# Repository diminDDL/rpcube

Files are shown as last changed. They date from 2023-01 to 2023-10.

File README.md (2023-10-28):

# rpcube

Welcome to `rpcube`, the ultimate compact solution for integrating the RP2040 into your designs seamlessly. This project presents an all-in-one small BGA package that brings the powerful RP2040 to your fingertips. 

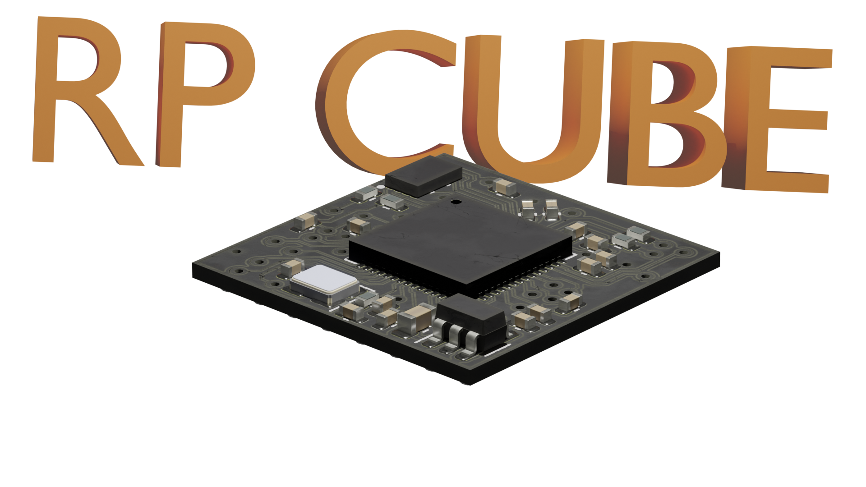
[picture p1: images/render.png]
rpcube Top View


## Features

- **Compact Size**: With a tiny footprint of just 16.5x16.5mm, `rpcube` is designed to fit into the smallest of spaces while providing the full capabilities of the RP2040.

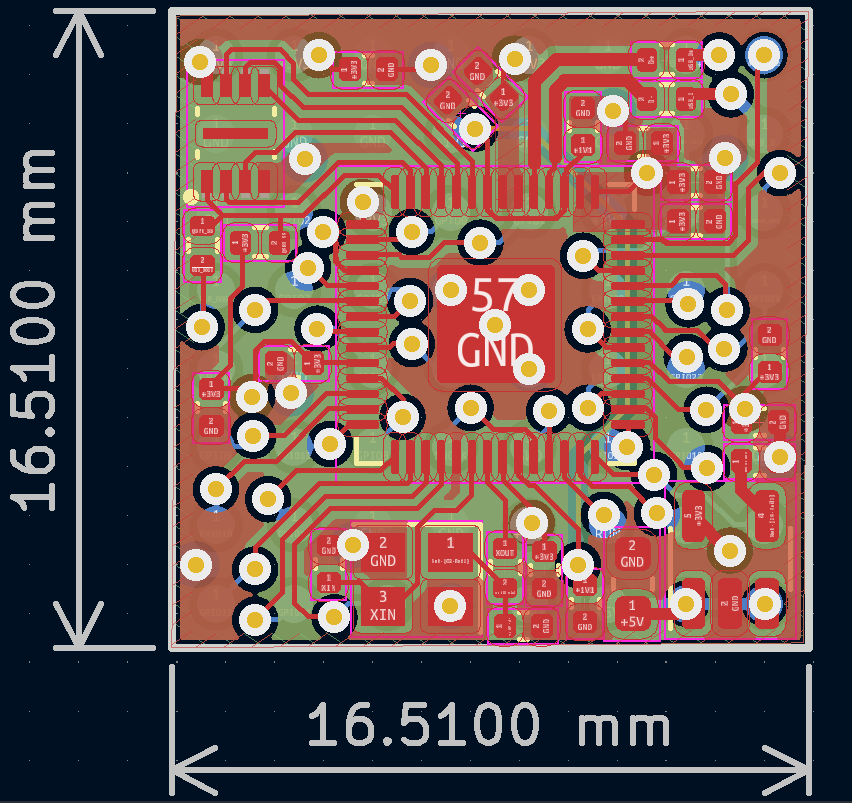
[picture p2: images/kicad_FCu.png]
rpcube Bottom View
  

- **Integrated Components**: The package includes EEPROM, all necessary bypass capacitors, and an LDO to allow for direct 5V input, stepping it down internally.
- **Full GPIO Access**: All GPIOs as well as the SWD lines of the RP2040 are exposed and accessible, ensuring you can leverage the full power of the microcontroller for your projects.
- **Versatile Assembly Options**: Whether you prefer to use solder paste and stencils or go for manual soldering with an iron, `rpcube` accommodates various assembly methods to suit your workflow:
  - **Top Side Assembly**: Begin by assembling the top side using solder paste and hot air or a reflow oven.
  - **Bottom Balls Creation**: Create the bottom balls using a soldering iron with flux and a substantial amount of solder, or stack several stencils to dispense ample solder paste, then blast it with hot air for balls to form.
  - **Target PCB Solder Paste Method**: You can use the same stencil as for the bottom side on the target board, or if you already have the balls done, use just a bit of flux and reflow, the balls will attach themselves.
  - **Target PCB Via in Pad Integration**: You can also use untented vias in your target PCB. Incorporate untented vias in the places of the balls and solder them one by one with an iron.
  - **Wire Attachment for Prototyping**: Alternatively, attach wires directly to `rpcube` for quick and easy point-to-point prototyping.

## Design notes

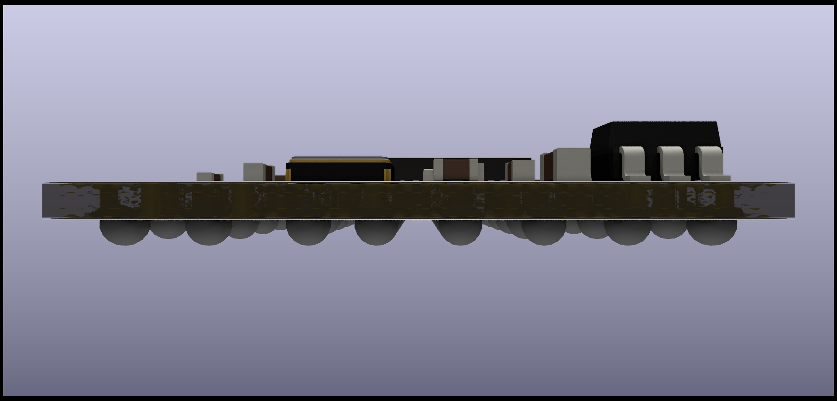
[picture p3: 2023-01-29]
images/3D_side.png

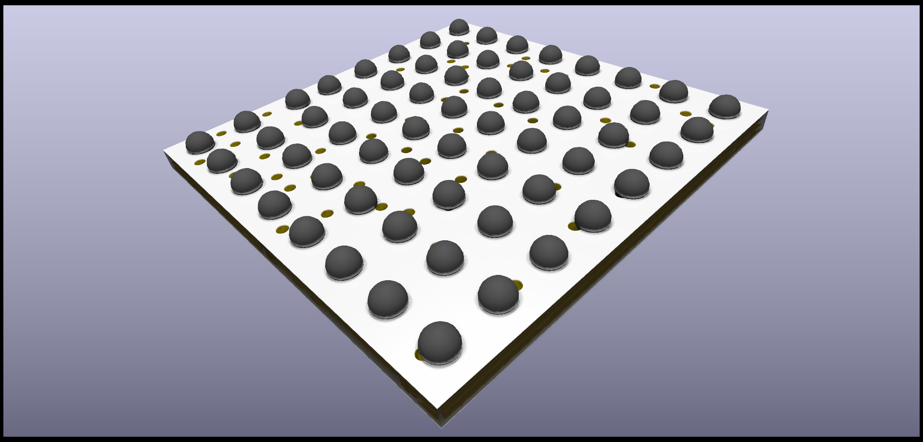
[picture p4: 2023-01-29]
images/3D_bottom.png

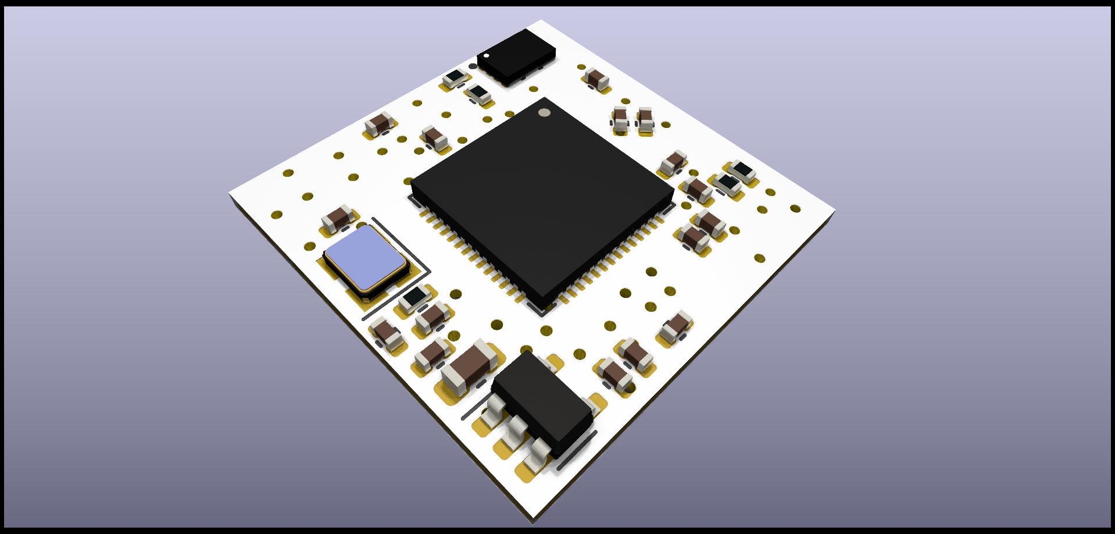
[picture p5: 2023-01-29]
images/3D_front.png

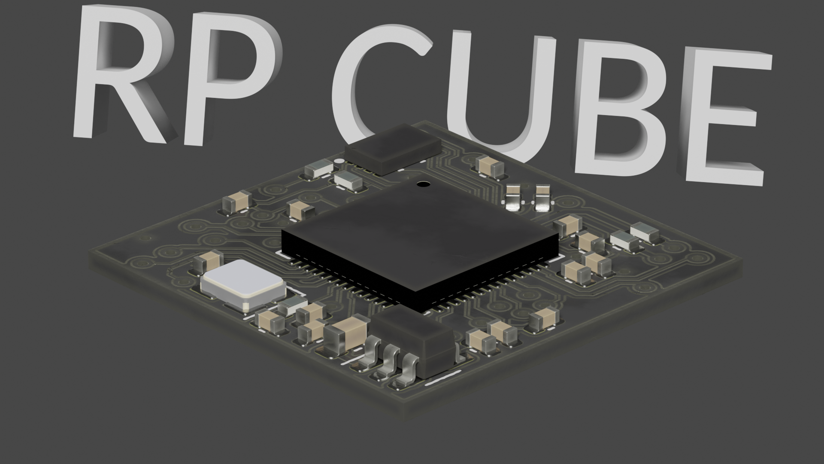
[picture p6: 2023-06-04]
images/untitled2.png

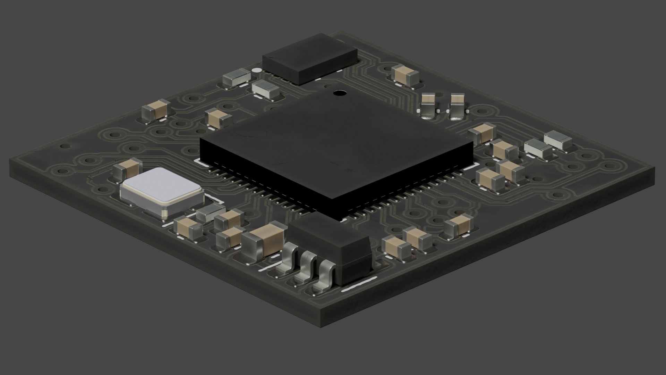
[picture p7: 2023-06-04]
images/untitled.png

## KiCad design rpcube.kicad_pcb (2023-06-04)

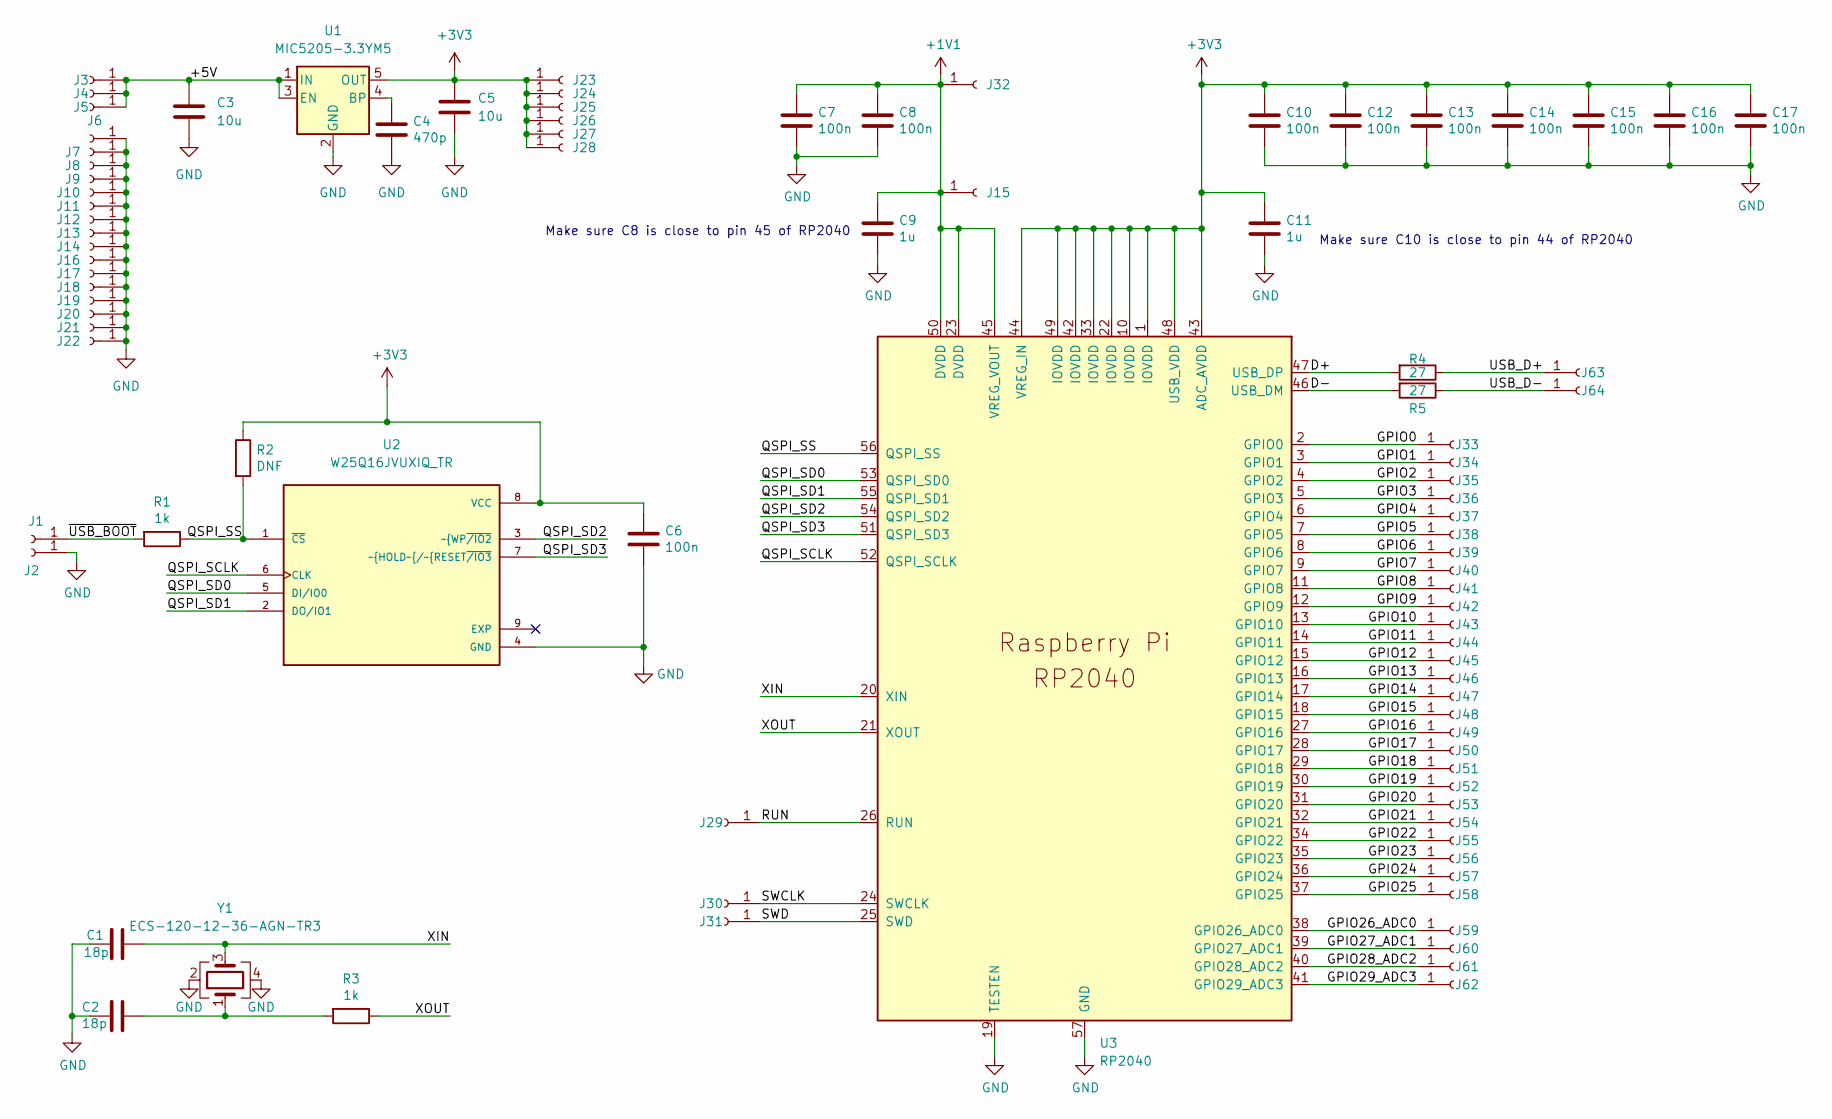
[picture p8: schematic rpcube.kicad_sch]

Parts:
C1, C2: 18p; C_0402_1005Metric
C3: 10u; C_0603_1608Metric
C4: 470p; C_0402_1005Metric
C5: 10u; C_0402_1005Metric
C6, C7, C8, C10, C12, C13, C14, C15, C16, C17: 100n; C_0402_1005Metric
C9, C11: 1u; C_0402_1005Metric
J1, J2, J3, J4, J5, J6, J7, J8, J9, J10, J11, J12, J13, J14, J15, J16, J17, J18, J19, J20, J21, J22, J23, J24, J25, J26, J27, J28, J29, J30, J31, J32, J33, J34, J35, J36, J37, J38, J39, J40, J41, J42, J43, J44, J45, J46, J47, J48, J49, J50, J51, J52, J53, J54, J55, J56, J57, J58, J59, J60, J61, J62, J63, J64: Conn_01x01_Female; BGA_PAD
R1, R3: 1k; R_0402_1005Metric
R2: DNF; R_0402_1005Metric
R4, R5: 27; R_0402_1005Metric
U1: MIC5205-3.3YM5; SOT-23-5
U2: W25Q16JVUXIQ_TR; IC_W25Q16JVUXIQ_TR; PARTREV H
U3: RP2040; RP2040-QFN-56
Y1: ECS-120-12-36-AGN-TR3; Crystal_SMD_2520-4Pin_2.5x2.0mm

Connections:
+1V1: C7.1, C8.1, C9.1, J15.1, J32.1, U3.23 (DVDD), U3.45 (VREG_VOUT), U3.50 (DVDD)
+3V3: C5.1, C6.1, C10.1, C11.1, C12.1, C13.1, C14.1, C15.1, C16.1, C17.1, J23.1, J24.1, J25.1, J26.1, J27.1, J28.1, R2.1, U1.5 (OUT), U2.8 (VCC), U3.1 (IOVDD), U3.10 (IOVDD), U3.22 (IOVDD), U3.33 (IOVDD), U3.42 (IOVDD), U3.43 (ADC_AVDD), U3.44 (VREG_IN), U3.48 (USB_VDD), U3.49 (IOVDD)
/+5V: C3.1, J3.1, J4.1, J5.1, U1.1 (IN), U1.3 (EN)
/D+: R4.2, U3.47 (USB_DP)
/D-: R5.2, U3.46 (USB_DM)
/GPIO0: J33.1, U3.2 (GPIO0)
/GPIO1: J34.1, U3.3 (GPIO1)
/GPIO2: J35.1, U3.4 (GPIO2)
/GPIO3: J36.1, U3.5 (GPIO3)
/GPIO4: J37.1, U3.6 (GPIO4)
/GPIO5: J38.1, U3.7 (GPIO5)
/GPIO6: J39.1, U3.8 (GPIO6)
/GPIO7: J40.1, U3.9 (GPIO7)
/GPIO8: J41.1, U3.11 (GPIO8)
/GPIO9: J42.1, U3.12 (GPIO9)
/GPIO10: J43.1, U3.13 (GPIO10)
/GPIO11: J44.1, U3.14 (GPIO11)
/GPIO12: J45.1, U3.15 (GPIO12)
/GPIO13: J46.1, U3.16 (GPIO13)
/GPIO14: J47.1, U3.17 (GPIO14)
/GPIO15: J48.1, U3.18 (GPIO15)
/GPIO16: J49.1, U3.27 (GPIO16)
/GPIO17: J50.1, U3.28 (GPIO17)
/GPIO18: J51.1, U3.29 (GPIO18)
/GPIO19: J52.1, U3.30 (GPIO19)
/GPIO20: J53.1, U3.31 (GPIO20)
/GPIO21: J54.1, U3.32 (GPIO21)
/GPIO22: J55.1, U3.34 (GPIO22)
/GPIO23: J56.1, U3.35 (GPIO23)
/GPIO24: J57.1, U3.36 (GPIO24)
/GPIO25: J58.1, U3.37 (GPIO25)
/GPIO26_ADC0: J59.1, U3.38 (GPIO26_ADC0)
/GPIO27_ADC1: J60.1, U3.39 (GPIO27_ADC1)
/GPIO28_ADC2: J61.1, U3.40 (GPIO28_ADC2)
/GPIO29_ADC3: J62.1, U3.41 (GPIO29_ADC3)
/QSPI_SCLK: U2.6 (CLK), U3.52 (QSPI_SCLK)
/QSPI_SD0: U2.5 (DI/IO0), U3.53 (QSPI_SD0)
/QSPI_SD1: U2.2 (DO/IO1), U3.55 (QSPI_SD1)
/QSPI_SD2: U2.3 (~WP~{/IO2), U3.54 (QSPI_SD2)
/QSPI_SD3: U2.7 (~HOLD~{/~{RESET~{/IO3), U3.51 (QSPI_SD3)
/QSPI_SS: R1.1, R2.2, U2.1 (~CS), U3.56 (QSPI_SS)
/RUN: J29.1, U3.26 (RUN)
/SWCLK: J30.1, U3.24 (SWCLK)
/SWD: J31.1, U3.25 (SWD)
/USB_D+: J63.1, R4.1
/USB_D-: J64.1, R5.1
/XIN: C1.1, U3.20 (XIN), Y1.3
/XOUT: R3.1, U3.21 (XOUT)
/~USB_BOOT: J1.1, R1.2
GND: C1.2, C2.2, C3.2, C4.2, C5.2, C6.2, C7.2, C8.2, C9.2, C10.2, C11.2, C12.2, C13.2, C14.2, C15.2, C16.2, C17.2, J2.1, J6.1, J7.1, J8.1, J9.1, J10.1, J11.1, J12.1, J13.1, J14.1, J16.1, J17.1, J18.1, J19.1, J20.1, J21.1, J22.1, U1.2 (GND), U2.4 (GND), U3.19 (TESTEN), U3.57 (GND), Y1.2, Y1.4
unnamed: C2.1, R3.2, Y1.1
unnamed: C4.1, U1.4 (BP)

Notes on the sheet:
Make sure C10 is close to pin 44 of RP2040
Make sure C8 is close to pin 45 of RP2040

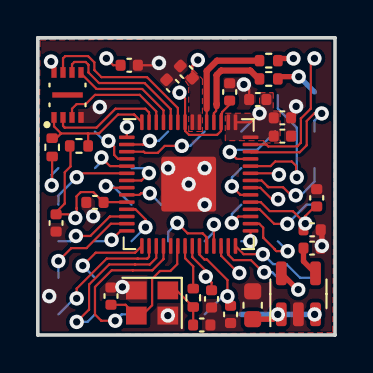
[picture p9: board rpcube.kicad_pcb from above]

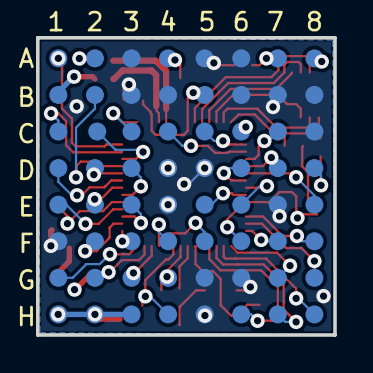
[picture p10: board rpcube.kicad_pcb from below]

Board: 4 copper layers, 16.5 x 16.5 mm, 90 parts (64 on the bottom side), 52 nets.

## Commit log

2023-01-29 finished PCB
    [rpcube.kicad_pcb, rpcube.kicad_sch]
2023-01-29 minor changes
    [rpcube.kicad_pcb]
2023-04-16 updated schematic
    [rpcube-B_Cu.gbl, rpcube-B_Mask.gbs, rpcube-B_Paste.gbp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]
2023-06-04 added more images
    [rpcube.kicad_pcb]
